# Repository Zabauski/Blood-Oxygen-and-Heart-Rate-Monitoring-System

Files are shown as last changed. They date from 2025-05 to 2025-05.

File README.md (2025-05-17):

# Blood Oxygen and Heart Rate Monitoring System

Design of a simple device for measuring heart rate and blood oxygen saturation (SpO₂) using a dedicated sensor, with live results displayed on an OLED screen. The device also signals when critical values are exceeded via an LED or an audible buzzer.

---

## Table of Contents

- [1  Project Plan](#1project-plan)
  - [1.1  Project Components](#11project-components)
- [2  Bill of Materials](#2bill-of-materials)
- [3  Operating Principle](#3operating-principle)
- [4  Schematics](#4schematics)
  - [4.1  Electrical Schematic (Fritzing)](#41electrical-schematic-fritzing)
  - [4.2  Wiring Diagram (KiCad)](#42wiring-diagram-kicad)
- [5 Project Implementation](#5-project-implementation)
  - [5.1 Stage 1 – Breadboard](#51-stage-1--breadboard)
  - [5.1 Stage 2 – Enclosure Modelling](#51-stage-2--enclosure-modelling)
  - [5.1 Stage 3 – Printing the Enclosure](#51-stage-3--printing-the-enclosure)
  - [5.1 Stage 4 – Assembling the Electronics](#51-stage-4--assembling-the-electronics)
  - [5.2 Software Implementation](#52software-implementation)
- [6 Summary](#6-summary)
- [7 Project Results](#7-project-results)
  - [7.1 Device Overview](#71-device-overview)
  - [7.2 Errors Encountered](#72-errors-encountered)
  - [7.3 Future Improvements](#73-future-improvements)

## 1  Project Plan

### 1.1  Project Components

1. **Microcontroller** (e.g., ESP32, Arduino Nano) – manages the project logic, communicates with the sensor and the display.
<p align="center">
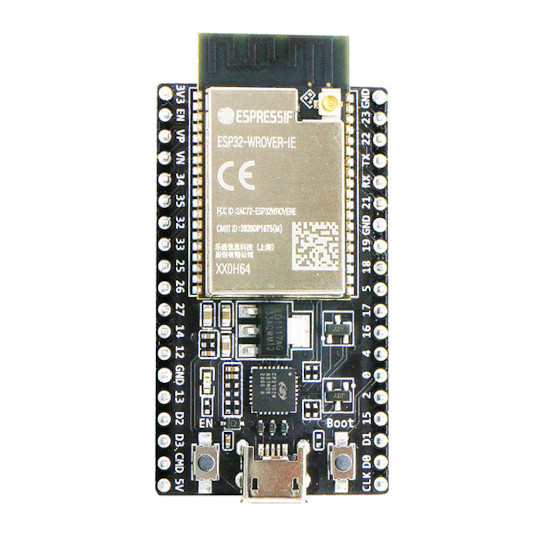
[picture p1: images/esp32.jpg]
ESP32
  
</p>

2. **Pulse‑oximetry sensor** (MAX30100 or MAX30102) – measures heart rate and blood oxygen saturation. The user places a finger on this compact module.
<p align="center">
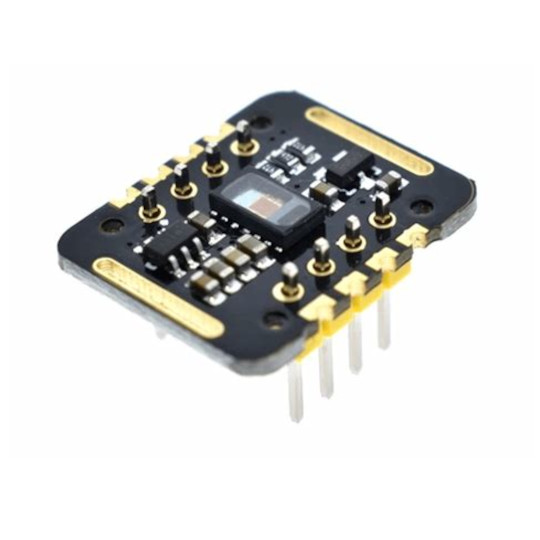
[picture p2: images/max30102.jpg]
MAX30102
  
</p>

3. **OLED display** (128 × 64 or similar, I²C/SPI) – shows the measurement results (pulse and SpO₂).
<p align="center">
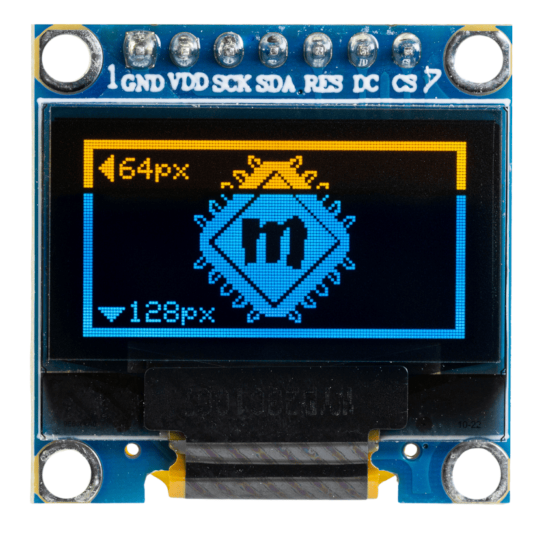
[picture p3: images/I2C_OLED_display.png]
OLED
  
</p>

4. **Wires and breadboard / prototype PCB** – used to interconnect the components and build the circuit.
<p align="center">
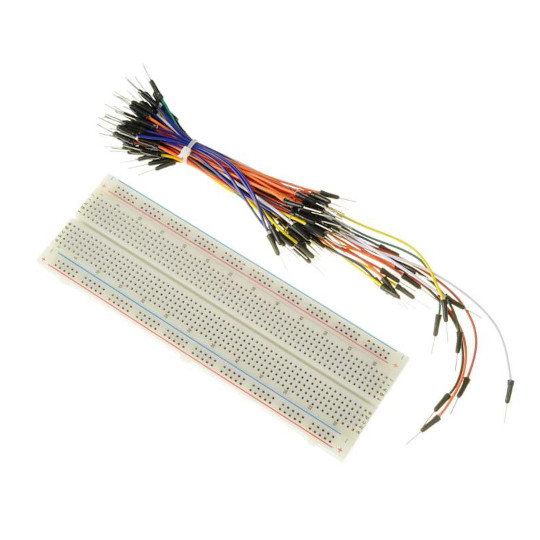
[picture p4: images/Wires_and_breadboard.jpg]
Wires
  
</p>

---

## 2  Bill of Materials

| Component | cost ($) | 
| --- | ---: |
| Microcontroller (ESP32) | ≈ 3.65| 
| MAX30102 sensor | ≈ 1.5 | 
| OLED display | ≈ 2  | 
| LEDs / buzzer | ≈ 5  | 
| Wires and prototyping board | ≈ 4  | 
| Solder flux | — | 
| PETG filament for enclosure | — | 
| **Total** | **≈ 16.15** | 

---

## 3  Operating Principle

1. **Measurement** – The user places a finger on the MAX30100/30102 module, which uses red and infrared light to detect variations in blood flow and oxygen saturatio.
2. **Data processing** – The ESP32 microcontroller reads raw values over the I²C bus, filters them, and calculates the current heart rate and SpO₂. 
3. **Live display** – Results are refreshed on the OLED screen in real time, e.g., *Pulse: 75 bpm  SpO₂: 98 %*. 
4. **Alarms** – If oxygen saturation drops below a safe threshold (≈ 90 %), the red LED flashes or the buzzer beeps to alert the user. 

---

## 4  Schematics

### 4.1  Electrical Schematic (Fritzing)

The breadboard‑level circuit diagram created in Fritzing shows how the sensor, display, LEDs and buzzer connect to the ESP32’s power rails and GPIO pins. 
<p align="center">
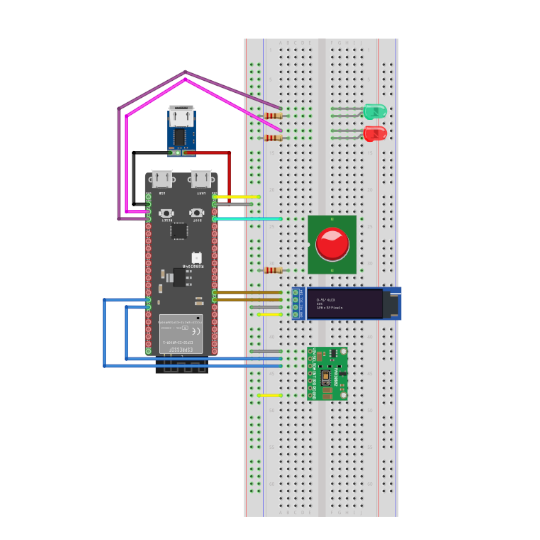
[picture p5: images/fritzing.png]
fritzing
  
</p>

<p align="center">
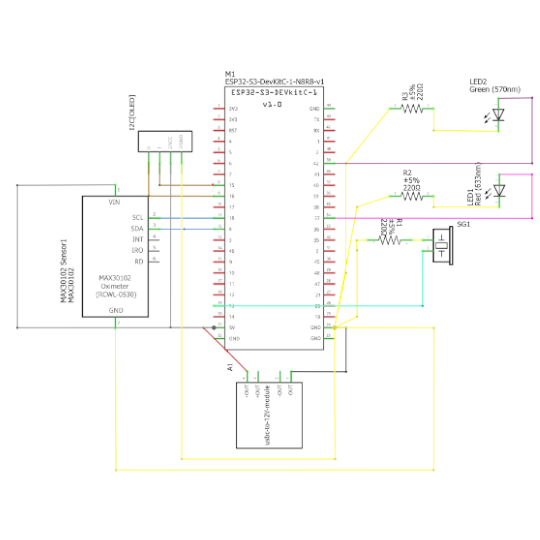
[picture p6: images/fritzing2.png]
fritzing2
  
</p>

### 4.2  Wiring Diagram (KiCad)
<p align="center">
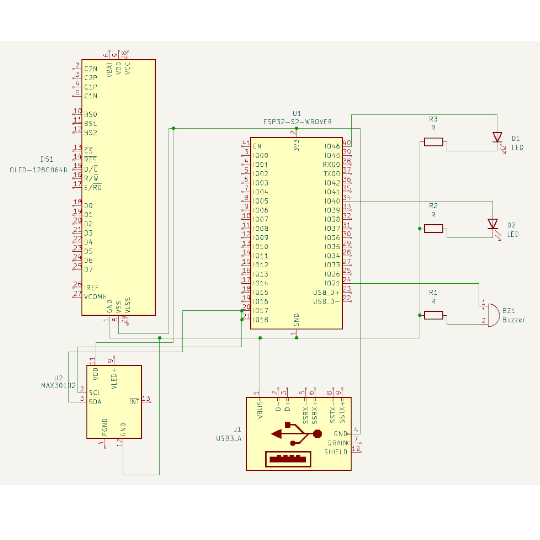
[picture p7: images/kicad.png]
kicad
  
</p>

---

## 5 Project Implementation

### 5.1 Stage 1 – Breadboard

<p align="center">
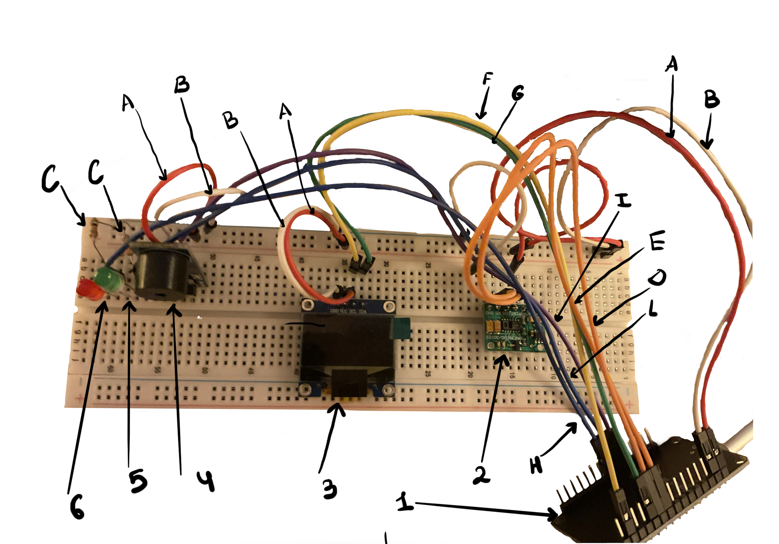
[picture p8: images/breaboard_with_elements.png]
breadboard with elements
  
</p>

The prototype was first built on a breadboard to verify all connections and ensure each part worked as intended. The setup included:

1. **ESP32 microcontroller** — receives sensor data and displays results  
2. **MAX30100 sensor** — initial module for heart-rate and blood-oxygen (SpO₂) measurement  
3. **OLED display (I²C)** — shows measurement results  
4. **Buzzer** — alarm signal  
5. **Green LED**  
6. **Red LED**

**Connections**

A. `ESP32 (3V3)` → `MAX30102 (VIN)`, `Buzzer (VCC)`, `OLED (VCC)`  
B. `ESP32 (GND)` → `MAX30102 (GND)`, `OLED (GND)`  
C. `ESP32 (GND)` → LED cathodes (via resistors)  
D. `ESP32 (D21)` → `MAX30102 (SDA)`  
E. `ESP32 (D22)` → `MAX30102 (SCL)`  
F. `ESP32 (D4)`  → `OLED (SDA)`  
G. `ESP32 (D5)`  → `OLED (SCL)`  
H. `ESP32 (D25)` → Red-LED anode  
I. `ESP32 (D27)` → Buzzer signal  
J. `ESP32 (D26)` → Green-LED anode  

---

### 5.1 Stage 2 – Enclosure Modelling

<p align="center">
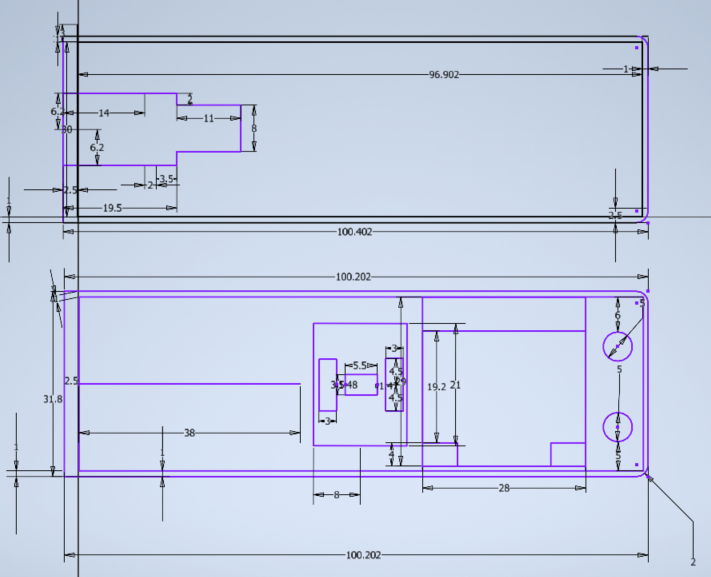
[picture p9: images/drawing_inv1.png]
flat drawing
  
</p> 

The flat sketch details all dimensions and mounting-hole positions for the ESP32, MAX30102, OLED display, and LEDs/buzzer. Seven design-print cycles were needed to correct misaligned holes and mismatched dimensions.

<p align="center">
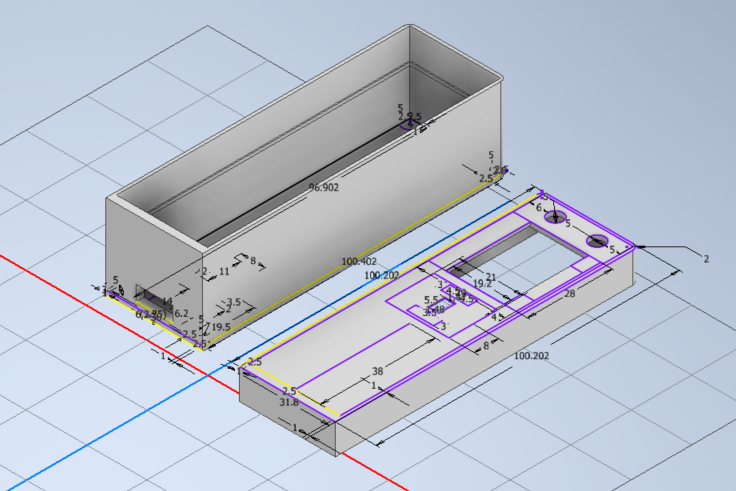
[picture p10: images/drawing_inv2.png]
  
</p> 

Body height was optimised to minimise PETG use while maintaining rigidity.

---

### 5.1 Stage 3 – Printing the Enclosure

Printed on a **Creality K1 Max** with white PETG.

**Print parameters**

- Filament: PETG, Ø 1.75 mm, white  
- Bed temp: 80 °C  Nozzle temp: 235 °C  
- Layer height: 0.20 mm Print speed: 150 mm/s  
- Infill: 20 % honeycomb Walls: 3  
- Cooling: from layer 3 Supports: *touching buildplate*

**Result**

≈ 2 h print time. The enclosure was defect-free; white PETG gave a clean matte finish.  

---

### 5.1 Stage 4 – Assembling the Electronics

<p align="center">
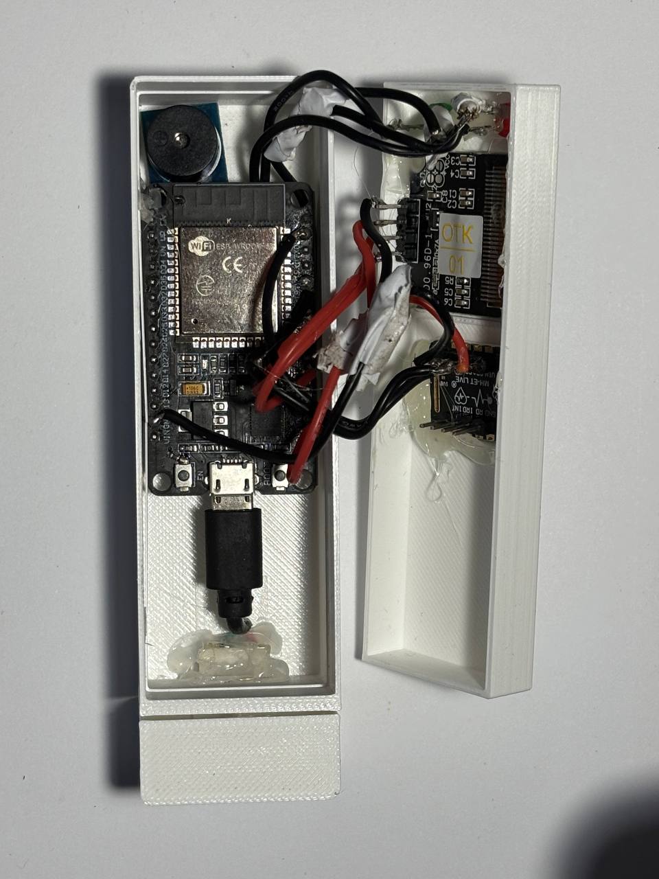
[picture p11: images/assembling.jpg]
  
</p>  

The circuit was transferred to the new housing, using freshly cut leads for neat solder joints.

- **Lower section:** Components placed and fixed with minimal hot-glue for easy maintenance.  
- **Upper lid:** Remaining parts glued to prevent movement.  
- **Power:** Shortened micro-USB → USB cable, hot-glued for strain relief.  ---

### 5.2 Software Implementation

**Introduction**

For serial communication with the **ESP32** board I use the **picocom** tool, which provides easy access to the serial port.

## Required MicroPython libraries

This project relies on two external modules that are **not** included in the
standard firmware:

- `micropython-ssd1306` – OLED driver  
- `micropython-max30102` – MAX30102 pulse-oximeter driver

### Quick install (board has Wi-Fi)

```bash
# Install MicroPython’s package manager if missing
pip install mip  # or 'upip', depending on your firmware

# Grab the libraries
mip install micropython-ssd1306
mip install micropython-max30102
```
[main.py](./main.py)

## 6 Summary

The entire system now works as intended: data are displayed on the OLED, the LEDs indicate status, and short audible alerts are triggered without interruptions.  
Keep in mind, however, that the **MAX30102** cannot match professional-grade accuracy. It measures red- and infrared-light reflectance, so skin thickness, blood-flow changes, or an imperfect finger position can cause noticeable reading fluctuations.

In the firmware I tuned several sensor parameters—for example, changing the LED amplitude  
`sensor.set_active_leds_amplitude(0x2F)`  
and the sample rate  
`sensor.set_sample_rate(200)`.  
These tweaks better align the sensor’s sensitivity with the test conditions but cannot fully eliminate noise. In practice, treat the readings as indicative values or for trend monitoring only.

From a software standpoint the solution already detects finger presence, reads pulse, estimates SpO₂, and presents the data clearly on the OLED. Further signal-filtering algorithms could improve stability and reliability. Nevertheless, the current implementation fulfils the core goals and provides a basis for more advanced experiments.

---

## 7 Project Results

### 7.1 Device Overview

The finished pulse- and oxygen-measurement device performed correctly in all tests.  
It comprises an ESP32, a MAX30102 sensor, an OLED display, and LED/buzzer indicators.  
Data are processed in real time and shown clearly on the OLED, but—because of the MAX30102’s limitations—accuracy is below medical-device standards.

<p align="center">
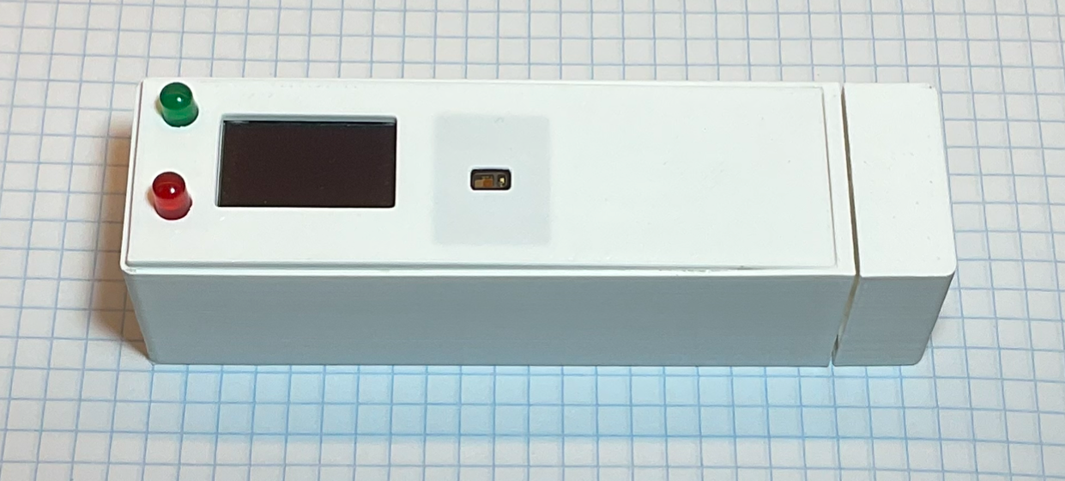
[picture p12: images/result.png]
result
  
</p>  

---

### 7.2 Errors Encountered

1. **Power-cable choice** – The cable used supported only power, not data, which blocked the planned WebUSB feature for online read-outs and logging.  
2. **Enclosure design mistakes** – Inexperience produced six design errors, forcing seven print attempts. The final case still has a slight bulge caused by internal cable pressure (Figure 7-2).

<p align="center">
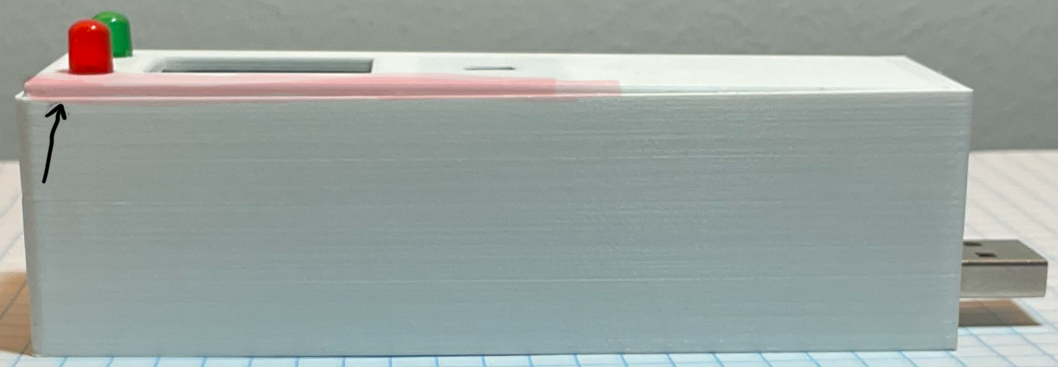
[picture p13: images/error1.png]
error
  
</p> 

---

### 7.3 Future Improvements

- Fix the issues above—especially selecting a cable that also carries data, enabling WebUSB functionality.  
- Shrink the enclosure by optimising component layout and removing unused space .
<p align="center">
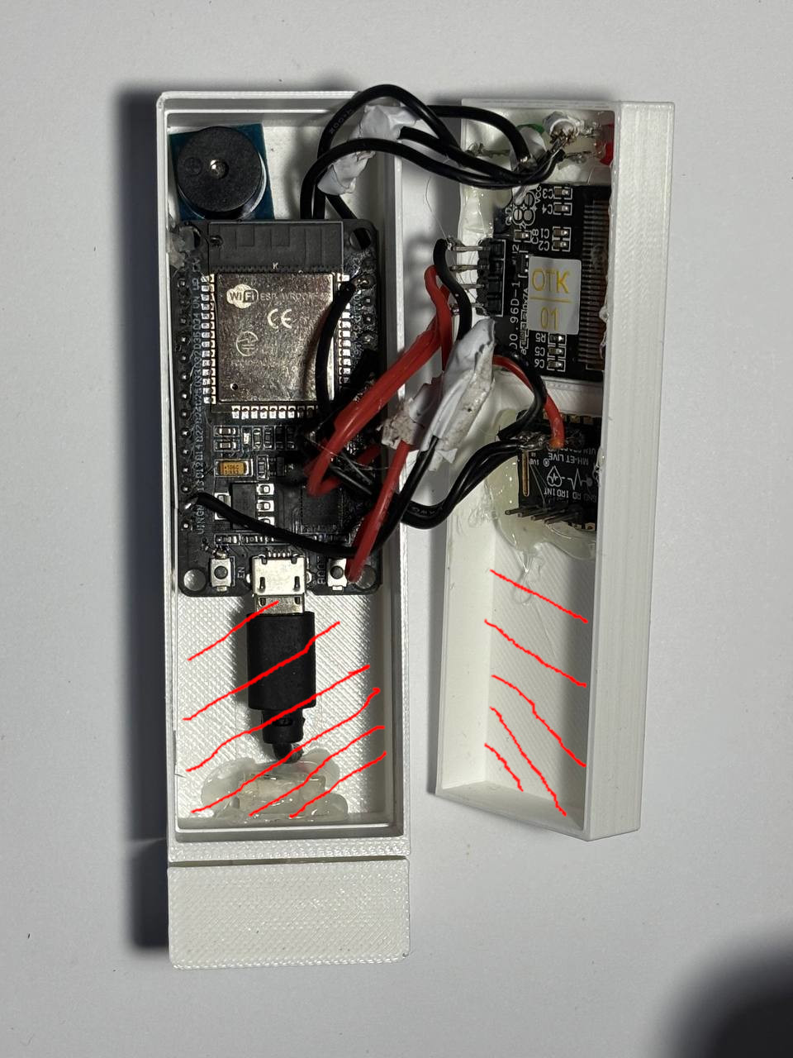
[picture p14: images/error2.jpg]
error
  
</p>

- Replace the ESP32 with a more compact microcontroller, allowing battery power.  
- Enhance signal-processing algorithms to increase measurement stability and accuracy.

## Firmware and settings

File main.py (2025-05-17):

from machine import SoftI2C, Pin
from ssd1306 import SSD1306_I2C
from max30102 import MAX30102
from utime import sleep, ticks_ms, ticks_diff

MIN_SIGNAL = 5000
HEART_RATE_LOW = 50
HEART_RATE_HIGH = 120

i2c_oled = SoftI2C(scl=Pin(5), sda=Pin(4), freq=400000)
oled = SSD1306_I2C(128, 64, i2c_oled)

i2c_sensor = SoftI2C(scl=Pin(22), sda=Pin(21), freq=400000)
sensor = MAX30102(i2c=i2c_sensor)

red_led = Pin(25, Pin.OUT)
green_led = Pin(26, Pin.OUT)
buzzer = Pin(27, Pin.OUT)

oled.fill(0)
oled.text("Initializing...", 0, 0)
oled.show()

if sensor.i2c_address not in i2c_sensor.scan():
    oled.fill(0)
    oled.text("MAX30102 Error!", 0, 0)
    oled.show()
    raise OSError("MAX30102 not detected")

sensor.setup_sensor()
sensor.set_fifo_average(4)
sensor.set_sample_rate(200)
sensor.set_active_leds_amplitude(0x2F)

oled.fill(0)
oled.text("MAX30102 Ready", 0, 0)
oled.show()

def calculate_heart_rate(timestamps):
    beats = len(timestamps)
    if beats < 2:
        return 0
    duration_ms = ticks_diff(timestamps[-1], timestamps[0])
    if duration_ms > 0:
        heart_rate = (beats / duration_ms) * 60000
        return int(heart_rate)
    return 0

def calculate_spo2(red_values, ir_values):
    if len(red_values) < 10 or len(ir_values) < 10:
        return None
    mean_red = sum(red_values) / len(red_values)
    mean_ir = sum(ir_values) / len(ir_values)
    ac_red = sum(abs(x - mean_red) for x in red_values) / len(red_values)
    ac_ir = sum(abs(x - mean_ir) for x in ir_values) / len(ir_values)
    if ac_ir == 0:
        return None
    ratio = (ac_red / mean_red) / (ac_ir / mean_ir)
    spo2 = 110 - 25 * ratio
    if spo2 < 0 or spo2 > 100:
        return None
    return int(spo2)

prev_ir = 0
is_rising = False
ir_timestamps = []

red_buffer = []
ir_buffer = []

in_alert_state = False

try:
    while True:
        sensor.check()
        if sensor.available():
            red = sensor.pop_red_from_storage()
            ir = sensor.pop_ir_from_storage()

            if ir < MIN_SIGNAL:
                oled.fill(0)
                oled.text("Place finger", 0, 0)
                oled.show()
                red_led.value(1)
                green_led.value(0)
                buzzer.value(1)
                sleep(0.2)
                buzzer.value(0)
                ir_timestamps.clear()
                red_buffer.clear()
                ir_buffer.clear()
                prev_ir = 0
                is_rising = False
                in_alert_state = False
            else:
                current_ir = ir
                if current_ir > prev_ir:
                    is_rising = True
                elif is_rising and current_ir < prev_ir:
                    ir_timestamps.append(ticks_ms())
                    if len(ir_timestamps) > 10:
                        ir_timestamps.pop(0)
                    is_rising = False
                prev_ir = current_ir

                red_buffer.append(red)
                ir_buffer.append(ir)
                if len(red_buffer) > 50:
                    red_buffer.pop(0)
                if len(ir_buffer) > 50:
                    ir_buffer.pop(0)

                heart_rate = calculate_heart_rate(ir_timestamps)
                spo2 = calculate_spo2(red_buffer, ir_buffer)

                oled.fill(0)
                oled.text("Pulse and O2", 0, 0)
                oled.text(f"Pulse: {heart_rate} bpm", 0, 20)
                if spo2 is not None:
                    oled.text(f"SpO2: {spo2}%", 0, 40)
                else:
                    oled.text("no data SpO2", 0, 40)
                oled.show()

                if HEART_RATE_LOW <= heart_rate <= HEART_RATE_HIGH:
                    buzzer.value(0)
                    green_led.value(1)
                    red_led.value(0)
                else:
                    green_led.value(0)
                    red_led.value(1)
                    buzzer.value(1)
                    sleep(0.2)
                    buzzer.value(0)
                    if not in_alert_state:
                        buzzer.value(1)
                        sleep(0.2)
                        buzzer.value(0)
                        in_alert_state = True
        sleep(0.1)
except KeyboardInterrupt:
    green_led.value(0)
    red_led.value(0)
    buzzer.value(0)
    oled.fill(0)
    oled.text("Program stopped", 0, 0)
    oled.show()
